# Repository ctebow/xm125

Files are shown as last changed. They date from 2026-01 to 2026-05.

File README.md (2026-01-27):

# XM125 Teensy Radar Project

This repository contains the files for a custom PCB project that integrates Acconeer's XM125 radar sensor with a Teensy microcontroller.

## Hardware

Here are some pictures of the physical setup.

### Front
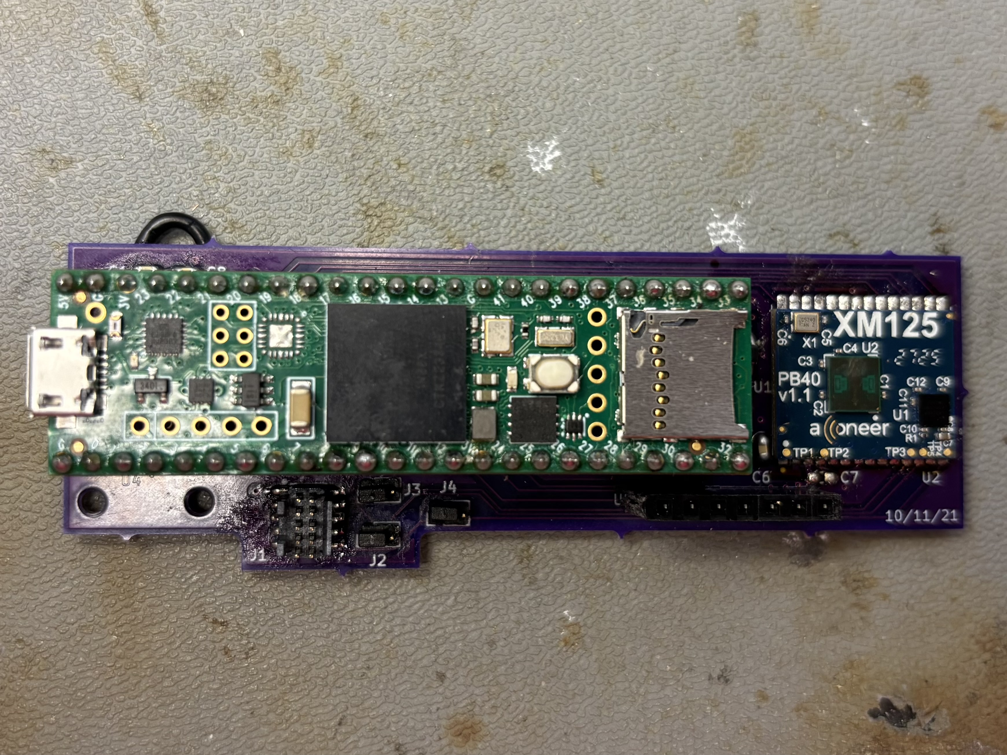
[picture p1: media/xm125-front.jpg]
Front View of the XM125 Teensy Setup


### Back
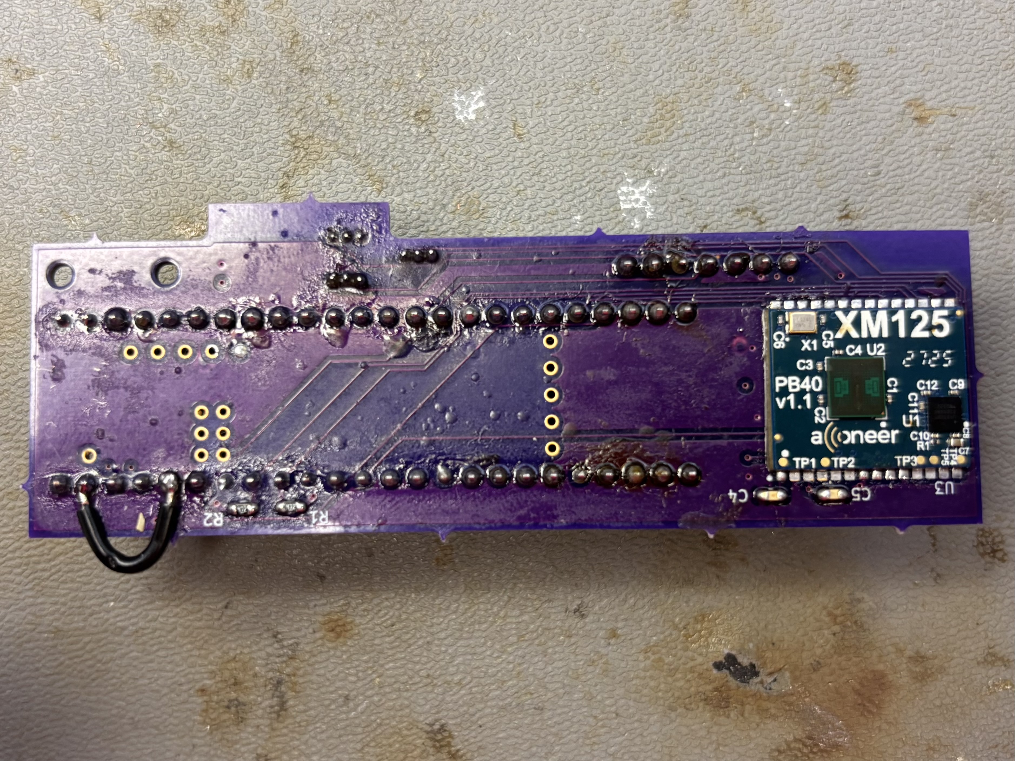
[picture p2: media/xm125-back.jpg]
Back View of the XM125 Teensy Setup


## PCB Schematic

The schematic for the custom PCB is shown below. This board breaks out the necessary connections for the XM125 radar sensor and provides a platform for development with a Teensy.

PCB Schematic

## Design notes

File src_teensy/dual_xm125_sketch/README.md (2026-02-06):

# Dual XM125 Sketch

Teensy sketch for two XM125 distance modules on I2C:

- **Front**: address 0x51, WAKE pin 20
- **Back**: address 0x52, WAKE pin 15

## Serial Protocol

Same protocol as `static_testing_sketch`, compatible with `benchmarking/scripts/serial_data_collection.py`:

- Send `START\n` to begin measurement loop
- Send `STOP\n` to end
- Each output line: `register rdistance strength` (space-separated)

**Register encoding:**

- `0–9`: Back sensor peaks 0–9  
- `10–19`: Front sensor peaks 0–9  

The Python script writes CSV: `trial, register, rdistance, strength, edistance`.

## Usage

1. Flash this sketch to a Teensy.
2. Wire both XM125 modules (front 0x51, back 0x52) and WAKE pins.
3. Run:

   ```bash
   python benchmarking/scripts/serial_data_collection.py -o output.csv -n 100 --num_trials 14 --edistance "200,190,180,170,160,150,140,130,120,110,100,90,80,70"
   ```

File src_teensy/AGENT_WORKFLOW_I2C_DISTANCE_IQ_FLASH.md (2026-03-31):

# Agent Workflow: I2C Distance + IQ on STM32L431 (FLASH Slimming)

## Context
- Target: `STM32L431CBYx` (128 KB FLASH, 64 KB RAM)
- Problem: Firmware build for an I2C Distance + IQ endpoint exceeded FLASH (initially ~112 bytes, later narrowed as refactors landed).
- Root cause of initial overflow: the IQ app duplicated large portions of the distance detector implementation in a second translation unit.

## Files & key building blocks used in the workflow
- Shared core API header (new): `Inc/i2c_distance_detector_core.h`
- Shared core implementation (new): `Src/applications/i2c/i2c_distance_detector_core.c`
- Custom trimmed core (new): `Src/applications/i2c/i2c_distance_detector_core_custom.c`
- Thin IQ endpoint app layer:
  - `Src/applications/i2c/i2c_iq_custom.c` (refactored to be a thin IQ endpoint on top of the core)
  - IQ stream variant exists in repo for reference:
    - `Src/applications/i2c/i2c_distance_iq_stream.c`
- I2C register protocol:
  - `Inc/distance_reg_protocol.h`
  - `Src/applications/i2c/distance_reg_protocol_access.c`

## Workflow steps (what to do, and why)
### 1) Stop duplication: split detector into “core + thin app”
Goal: ensure the distance detector logic is compiled once into FLASH.

Approach:
- Move detector lifecycle, state, and default command handling into:
  - `i2c_distance_detector_core.c`
- Make app selection work via weak symbols:
  - core provides default detector API behavior
  - IQ endpoint app provides strong overrides for IQ-specific command/data/status behaviors

### 2) Resolve “multiple definition” linker errors (weak exports)
Symptom:
- `multiple definition of i2c_distance_detector_*` when both core and an app compiled strong definitions.

Fix strategy:
- Mark core’s exported detector API functions as `__attribute__((weak))` so the app’s strong versions can override them.
- Ensure each CubeIDE configuration links exactly one “core” implementation object:
  - either `i2c_distance_detector_core.c` or `i2c_distance_detector_core_custom.c`, but not both.

### 3) Verify map evidence instead of guessing
Primary tool:
- CubeIDE link map file: `Debug/xm125.map`

What to inspect:
- `.rodata` contributors to understand string/format-string blowups.
- `_sidata` load address and `.data` section sizing to understand when the binary exceeds FLASH due to init-data placement.

Key realizations during this workflow:
- The custom IQ app’s `.rodata` was significantly larger than the stock detector app.
- After structural refactors and `.rodata` trimming, the failure mode shifted from `.rodata` overflow to `.data` load placement overflow.
- Remaining overflow can still be caused by library/code pulled in by IQ capture/processing paths.

### 4) Trim the remaining optional core features without touching the original core
New file introduced:
- `Src/applications/i2c/i2c_distance_detector_core_custom.c`

High-confidence cuts applied in the custom core:
- Removed auto “measure on wakeup” behavior.
- Removed UART log toggling and verbose logging paths (measurement print became a no-op).
- Removed config logging command support.
- Kept the critical detector lifecycle:
  - create config + sensor
  - apply config
  - calibrate / recalibrate
  - handle `MEASURE_DISTANCE`
  - maintain status and call `i2c_distance_detector_core_on_measurement_done()`

### 5) Handle “debug build warnings” safely
Warnings encountered:
- `is_detector_ready` defined but not used (`-Wunused-function`)
- ELF `LOAD segment with RWX permissions`

Guidance:
- If code paths were removed intentionally (e.g., wakeup auto-measure), unused helpers are expected.
- RWX load segment warnings are typical in bare-metal firmware with linker script memory permission attributes; ensure you’re not actually executing from `.data`.

## “Agent checklist” for future builds
1. Confirm your CubeIDE build links the intended core object and only one core object.
2. If link errors occur:
   - multiple definitions: apply weak-export strategy on the core side
   - FLASH overflow: inspect `Debug/xm125.map` for top `.rodata` and `.data` contributors
3. Cut optional features first (wakeup behavior, config logging, UART toggles).
4. Prefer structural sharing (core vs thin app) over string-only trimming.
5. When you get close (tens to hundreds of bytes):
   - compare `_sidata`, `.rodata`, and library pull-in (e.g., float/math paths) via the map.

## Summary of what was changed/added in this workflow
- Added: `Inc/i2c_distance_detector_core.h`
- Added: `Src/applications/i2c/i2c_distance_detector_core.c`
- Added: `Src/applications/i2c/i2c_distance_detector_core_custom.c` (trimmed optional features)
- Edited: `Src/applications/i2c/i2c_iq_custom.c` to become thin on top of the core
- Adjusted: core exported detector API functions to be `weak` to prevent multiple definition conflicts

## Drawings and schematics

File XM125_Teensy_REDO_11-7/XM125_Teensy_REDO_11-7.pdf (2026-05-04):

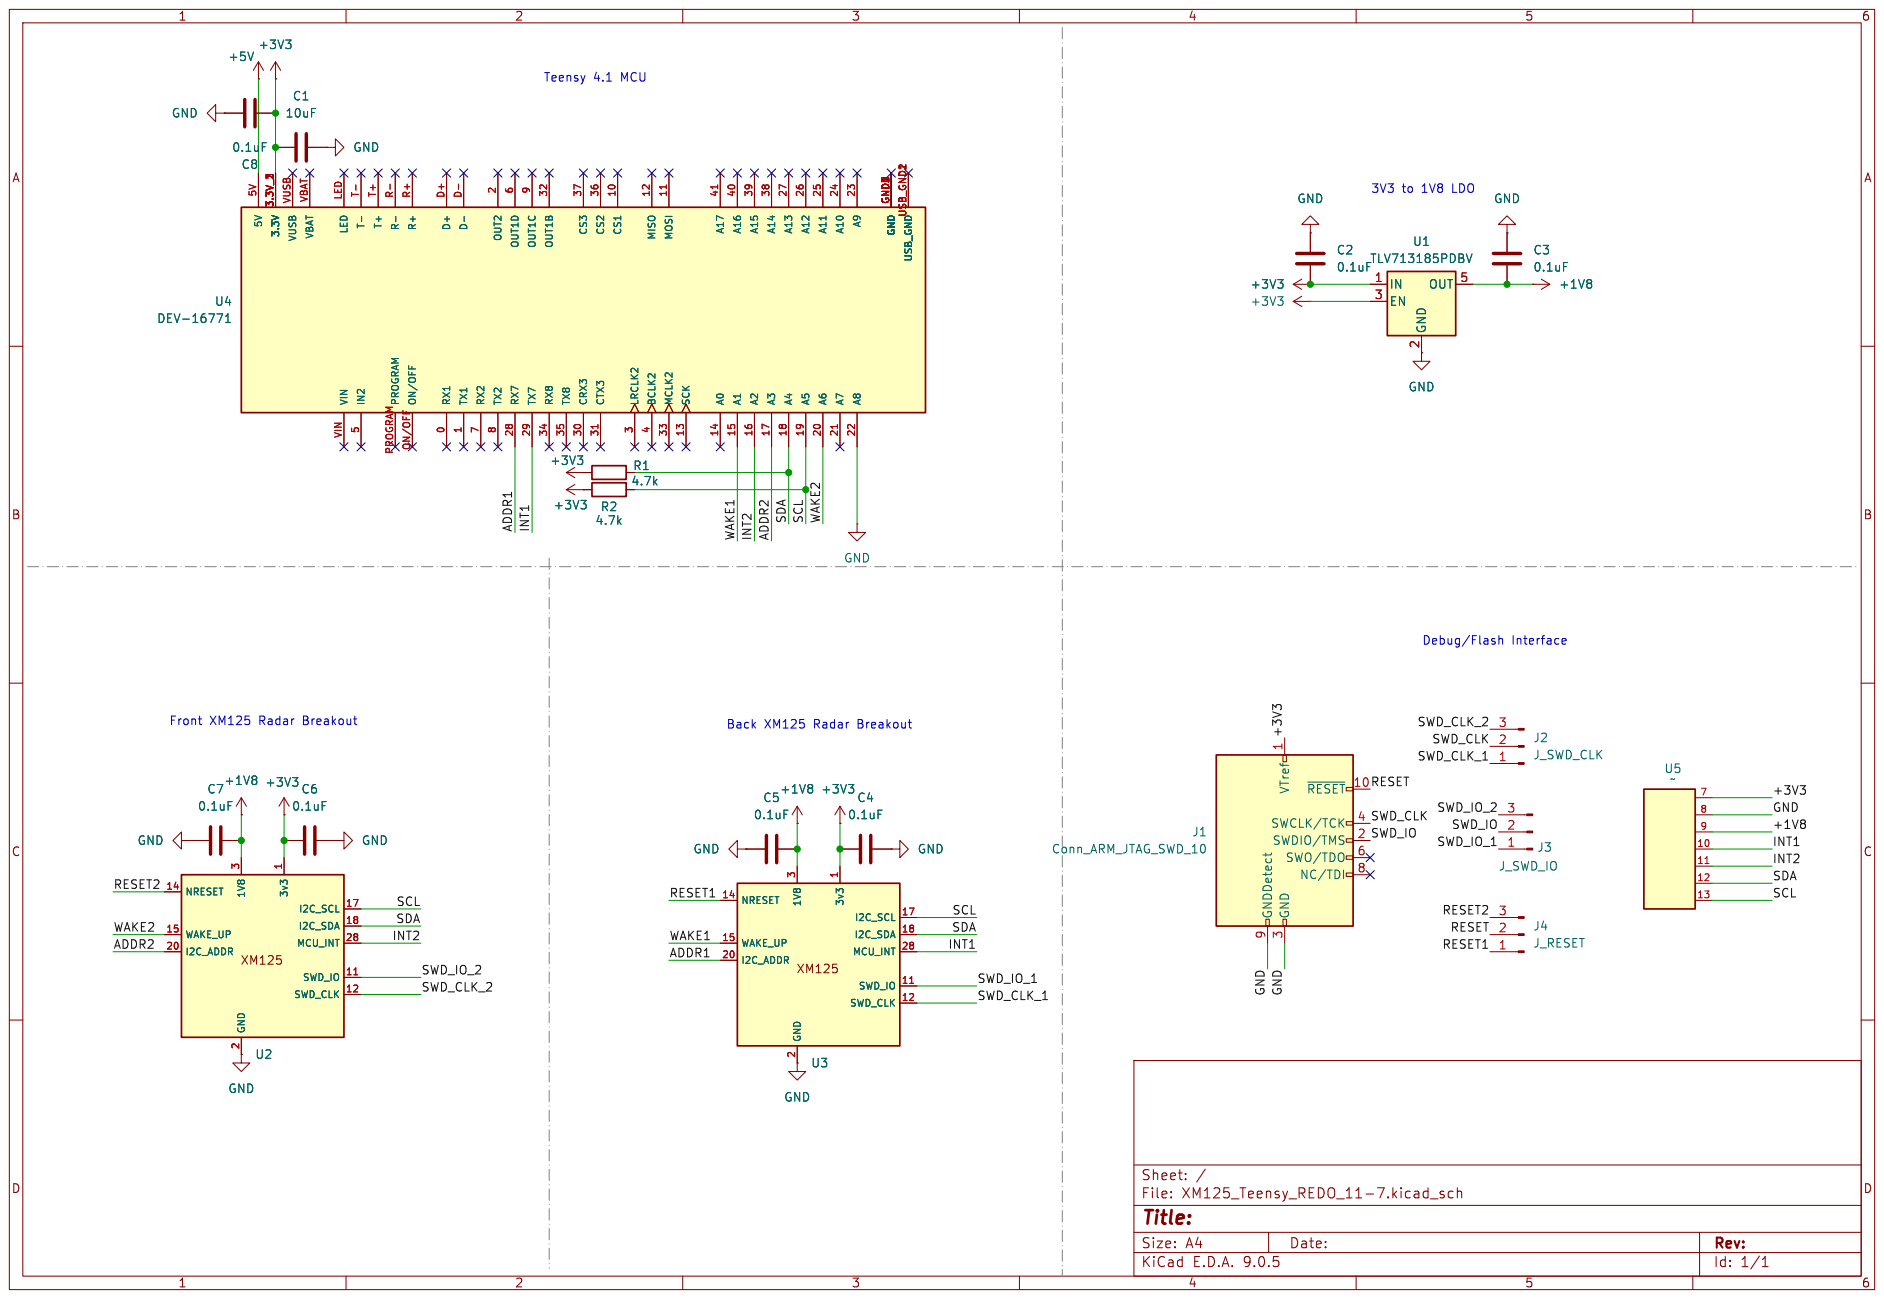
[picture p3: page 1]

4 MCLK2 33 SCK 13 A0 14 A1 15 A2 16 A3 17 A4 18 A5 19 A6 20 A7 21 A8 22 5V 5V 3.3V 3.3V_12 3.3V_3 VUSB VUSB VBAT VBAT LED LED T- T- T+ T+ R- R- R+ R+ D+ D+ D- D- OUT2

5 PROGRAM PROGRAMON/OFF ON/OFF RX1

3 ~{RESET}10 SWCLK/TCK 4 SWDIO/TMS 2 SWO/TDO 6 NC/TDI 8

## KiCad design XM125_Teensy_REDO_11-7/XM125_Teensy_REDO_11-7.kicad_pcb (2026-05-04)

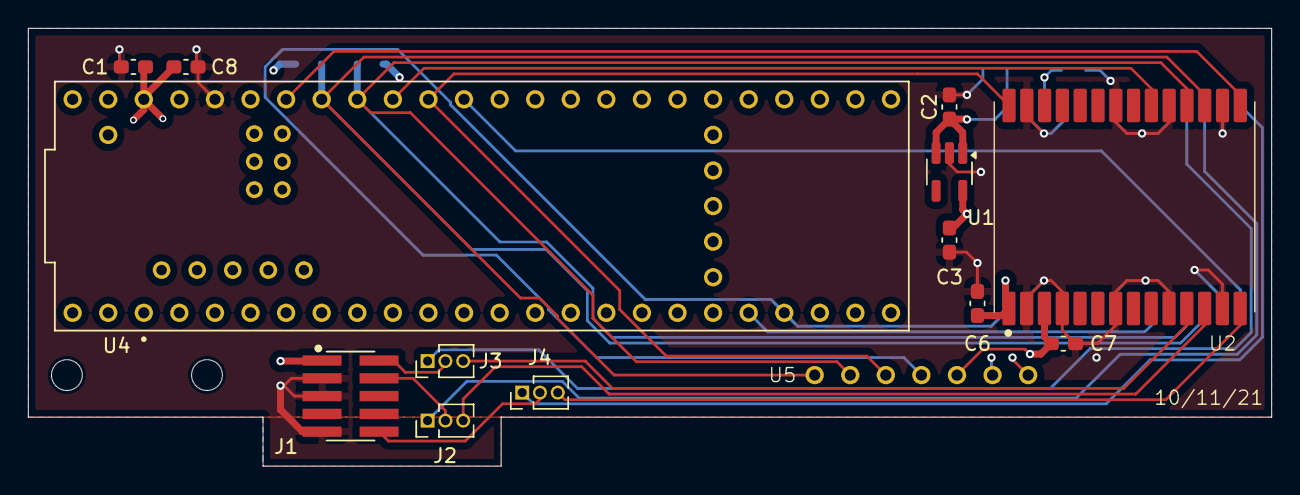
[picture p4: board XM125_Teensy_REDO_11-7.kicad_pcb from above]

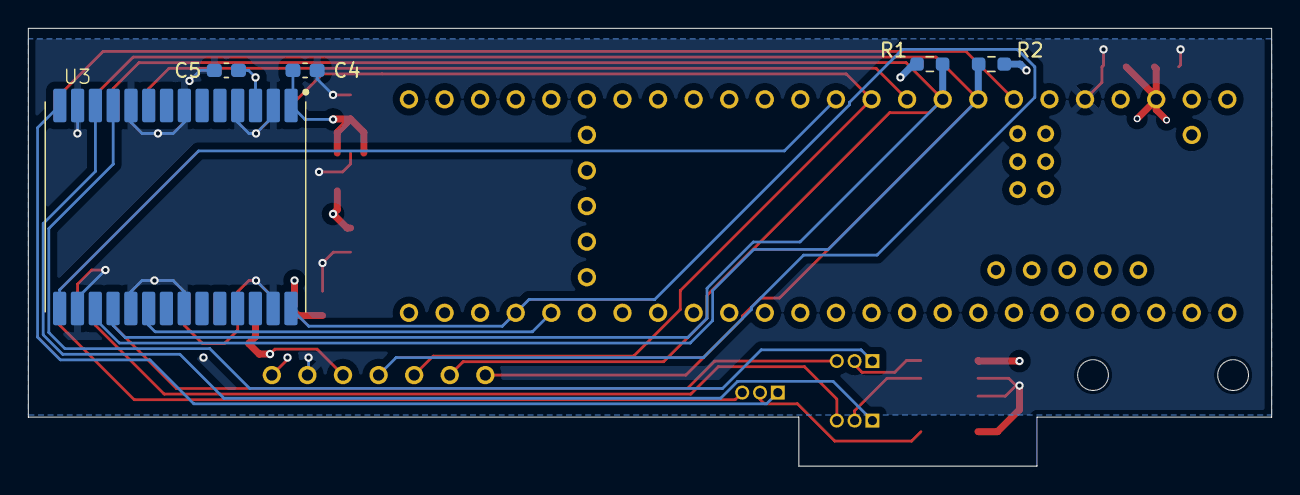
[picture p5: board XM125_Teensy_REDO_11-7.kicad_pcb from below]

Board: 4 copper layers, 88.8 x 31.2 mm, 19 parts (5 on the bottom side), 20 nets.

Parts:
C1: 10uF; C_0603_1608Metric_Pad1.08x0.95mm_HandSolder
C2, C3, C4, C5, C6, C7, C8: 0.1uF; C_0603_1608Metric_Pad1.08x0.95mm_HandSolder
J1: Conn_ARM_JTAG_SWD_10; FTS-105-03-L-DV
J2: J_SWD_CLK; PinHeader_1x03_P1.27mm_Vertical
J3: J_SWD_IO; PinHeader_1x03_P1.27mm_Vertical
J4: J_RESET; PinHeader_1x03_P1.27mm_Vertical
R1, R2: 4.7k; R_0603_1608Metric_Pad0.98x0.95mm_HandSolder
U1: TLV713185PDBV; SOT-23-5_HandSoldering
U2, U3: XM125
U4: DEV-16771; MODULE_DEV-16771
U5: Debug

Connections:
+1V8: C3.1, C5.1, C7.1, U1.5 (OUT), U2.3 (1V8), U3.3 (1V8), U5.9
+3V3: C1.1, C2.1, C4.2, C6.2, C8.1, J1.1 (VTref), R1.1, R2.1, U1.1 (IN), U1.3 (EN), U2.1 (3v3), U3.1 (3v3), U4.3.3V_1 (3.3V), U4.3.3V_2 (3.3V), U4.3.3V_3 (3.3V), U5.7
/ADDR1: U3.20 (I2C_ADDR), U4.28 (RX7)
/ADDR2: U2.20 (I2C_ADDR), U4.17 (A3)
/INT1: U3.28 (MCU_INT), U4.29 (TX7), U5.10
/INT2: U2.28 (MCU_INT), U4.16 (A2), U5.11
/RESET: J1.10 (~RESET), J4.2
/RESET1: J4.1, U3.14 (NRESET)
/RESET2: J4.3, U2.14 (NRESET)
/SCL: R2.2, U2.17 (I2C_SCL), U3.17 (I2C_SCL), U4.19 (A5), U5.13
/SDA: R1.2, U2.18 (I2C_SDA), U3.18 (I2C_SDA), U4.18 (A4), U5.12
/SWD_CLK: J1.4 (SWCLK/TCK), J2.2
/SWD_CLK_1: J2.1, U3.12 (SWD_CLK)
/SWD_CLK_2: J2.3, U2.12 (SWD_CLK)
/SWD_IO: J1.2 (SWDIO/TMS), J3.2
/SWD_IO_1: J3.1, U3.11 (SWD_IO)
/SWD_IO_2: J3.3, U2.11 (SWD_IO)
/WAKE1: U3.15 (WAKE_UP), U4.15 (A1)
/WAKE2: U2.15 (WAKE_UP), U4.20 (A6)
GND: C1.2, C2.2, C3.2, C4.1, C5.2, C6.1, C7.2, C8.2, J1.3 (GND), J1.5 (GND), J1.9 (GNDDetect), U1.2 (GND), U2.2 (GND), U2.4 (GND), U2.7 (GND), U2.10 (GND), U2.13 (GND), U2.16 (GND), U2.19 (GND), U2.22 (GND), U2.27 (GND), U3.2 (GND), U3.4 (GND), U3.7 (GND), U3.10 (GND), U3.13 (GND), U3.16 (GND), U3.19 (GND), U3.22 (GND), U3.27 (GND), U4.22 (A8), U5.8

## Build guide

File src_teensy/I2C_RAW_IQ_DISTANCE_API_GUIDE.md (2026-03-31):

# High-Level API Guide: Requesting Raw IQ Distance Frames over I2C

## What this guide covers
- The MCU/host communicates with the STM32 firmware via the I2C “distance detector” register protocol.
- This project supports two IQ endpoint styles:
  - `i2c_iq_custom.c`: IQ request is index-based (you request a bin/index and firmware captures and selects that index).
  - `i2c_distance_iq_stream.c`: IQ request is “capture once, then stream packed IQ samples”.

The register map comes from:
- `Inc/distance_reg_protocol.h`
- `Src/applications/i2c/distance_reg_protocol_access.c`

## Register addresses (subset)
- `DISTANCE_REG_COMMAND_ADDRESS` = `256`
- `DISTANCE_REG_DETECTOR_STATUS_ADDRESS` = `3`
- `DISTANCE_REG_MEASURE_COUNTER_ADDRESS` = `2`
- `DISTANCE_REG_PEAK0_DISTANCE_ADDRESS` = `17`
- `DISTANCE_REG_PEAK0_STRENGTH_ADDRESS` = `27`

## Command write behavior
- Writing a 32-bit value to `DISTANCE_REG_COMMAND_ADDRESS` triggers `i2c_distance_detector_command(value)`.
- Firmware sets a BUSY bit in detector status while processing.
- Host should wait until BUSY clears before reading results.

## IQ readiness signaling
- IQ readiness is communicated via bit `1<<16` in `DISTANCE_REG_DETECTOR_STATUS_ADDRESS`.
- Different IQ endpoint styles use different packing for the actual IQ samples, but the “IQ-ready bit” concept is consistent.

## IQ endpoint style A: `i2c_iq_custom.c` (index-based I/Q)
### IQ request format
- IQ command is written using:
  - upper 16 bits: `IQ_CMD_BASE` (value `6`)
  - lower 16 bits: requested `index`
- Firmware captures IQ and stores averaged IQ for all bins, then sets:
  - “current index” = requested index

### Sequence (one IQ bin)
1. Ensure detector is configured & calibrated for distance measurements.
2. Write command word to `DISTANCE_REG_COMMAND_ADDRESS`:
   - `command = (6<<16) | index`
3. Wait for the detector BUSY bit to clear.
4. Poll/read:
   - `DISTANCE_REG_DETECTOR_STATUS_ADDRESS` and confirm IQ-ready bit is set.
5. Read:
   - `DISTANCE_REG_MEASURE_COUNTER_ADDRESS`:
     - in this endpoint style it returns `iq_num_points` (#bins) when IQ is valid
   - `DISTANCE_REG_PEAK0_DISTANCE_ADDRESS`:
     - returns IQ “real” for the selected `index`
   - `DISTANCE_REG_PEAK0_STRENGTH_ADDRESS`:
     - returns IQ “imag” for the selected `index`

### Scaling of IQ values
- The protocol converts firmware `float` values to register values using `acc_reg_protocol_float_to_uint32_milli` / `acc_reg_protocol_float_to_int32_milli`.
- Practically:
  - divide read register integers by `1000` to recover the `float` IQ real/imag values.

### Getting a full IQ frame
- This endpoint style re-captures when you send a new IQ command.
- To retrieve the whole IQ frame, loop `index = 0 .. (iq_num_points-1)` and repeat the command + read steps for each index.

## IQ endpoint style B: `i2c_distance_iq_stream.c` (capture-once, stream packed IQ)
### IQ request format
- Firmware supports a command value `CAPTURE_IQ` with numeric value `6`.
- Host writes `DISTANCE_REG_COMMAND_ADDRESS = 6` to trigger capture.

### Sequence (capture once, then stream)
1. Ensure detector is configured & calibrated.
2. Write command:
   - `DISTANCE_REG_COMMAND_ADDRESS = 6`
3. Wait for IQ-ready bit to be set in `DISTANCE_REG_DETECTOR_STATUS_ADDRESS`.
4. Read `DISTANCE_REG_MEASURE_COUNTER_ADDRESS`:
   - IQ_METADATA is packed into this register:
     - valid bit (bit 31)
     - frame length (bits 0–15 in 16-bit words)
     - number of sweeps (bits 16–23)
     - data format (bits 24–29)
5. Stream IQ samples using `DISTANCE_REG_PEAK0_DISTANCE_ADDRESS` reads:
   - Each read returns a packed 32-bit word interpreted by firmware as:
     - low 16 bits = I (real)
     - high 16 bits = Q (imag)
   - The firmware returns a `float` that the protocol converts back to the packed integer, so host receives the packed IQ directly in the register value.

## Practical notes
- If you are optimizing for firmware size, prefer the “core + thin app” approach already used in this repo.
- If timing is critical, use the IQ stream style (capture once, stream many reads) rather than index-based repeated captures.

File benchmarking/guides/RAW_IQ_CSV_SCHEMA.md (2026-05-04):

# Raw IQ CSV schema

CSV files produced by [`benchmarking/scripts/get_iq_main.py`](../scripts/get_iq_main.py) when collecting from Teensy firmware [`raw_iq_xm125`](../../src_teensy/raw_iq_xm125/raw_iq_xm125.ino) (START/STOP) and [`RawI2CIqProtocol.h`](../../src_teensy/raw_iq_xm125/RawI2CIqProtocol.h) serial framing.

## File format

| Property | Value |
|---|---|
| **Encoding** | UTF-8 |
| **Delimiter** | Comma (`,`) |
| **Header row** | Yes — first row is the column header |
| **Row grain** | One row per **range bin** (one `bin_index I Q` line from serial) |

## Column definitions

Columns appear in this **fixed order**:

| # | Column | Type | Description |
|---|---|---|---|
| 1 | `trial` | integer | 0-based collection trial index (`--trials`). |
| 2 | `host_frame_id` | string | Teensy `frameCounter` from the `FRAME` serial line (host-side frame counter). |
| 3 | `sensor` | string | Sensor label from `FRAME`, e.g. `BACK`, `FRONT`. |
| 4 | `i2c_addr_hex` | string | Value after `addr=` on `FRAME` (hex digits without `0x` prefix in the cell, matching firmware print). |
| 5 | `bins` | string | Value after `bins=` on `FRAME`: number of bins in that IQ frame. |
| 6 | `firmware_frame_id` | string | Value after `fid=` on `FRAME`: STM firmware IQ cache frame id. |
| 7 | `t_ms` | string | Value after `t_ms=` on `FRAME`: Teensy `millis()` when the frame header was printed. |
| 8 | `bin_index` | string or numeric | First field of the bin line — global register index (back often `0..N-1`; front continues from `N` when both sensors are enabled). |
| 9 | `I` | float | In-phase component (Teensy sends floats already scaled from register milli-units). |
| 10 | `Q` | float | Quadrature component (same as `I`). |
| 11 | `expected_distance_mm` | float or empty | Optional experiment metadata from `--expected-distance-mm` for that trial; **empty** if not supplied. |

## Serial mapping

Teensy prints:

1. **Frame header:** `FRAME <host_frame_id> <SENSOR> addr=0xXX bins=<N> fid=<firmware_fid> t_ms=<millis>`
2. **Bin rows:** `<bin_index> <I> <Q>` (repeated `bins` times)
3. **Frame footer:** `ENDFRAME <host_frame_id> <SENSOR>`

Each bin row becomes one CSV row. Metadata columns (`host_frame_id` through `t_ms`) are **duplicated** from the most recent `FRAME` line so analysis does not need to join separate metadata files.

## Collection modes

| Mode | CLI | Row selection |
|---|-----|---|
| By IQ frames | `--num-iq-frames N` | Only bin rows **between** a `FRAME` and matching `ENDFRAME`; stop after `N` complete frame blocks. |
| By bin count | `--num-bin-rows N` | Stop after `N` bin rows. If no `FRAME` has been seen yet, frame metadata columns may be **empty** until the first `FRAME` is parsed. |

## Grouping for analysis

Treat rows as belonging to one **logical IQ frame** when they share the same:

- `trial`
- `host_frame_id`
- `sensor`
- `firmware_frame_id` (and typically the same `bins` and `t_ms` from that `FRAME`)

Across bins within that frame, `firmware_frame_id` should stay constant for a coherent cached capture on the STM side.

## Example header row

```csv
trial,host_frame_id,sensor,i2c_addr_hex,bins,firmware_frame_id,t_ms,bin_index,I,Q,expected_distance_mm
```

## Related

- I2C / firmware IQ protocol: [I2C_RAW_IQ_DISTANCE_API_GUIDE.md](I2C_RAW_IQ_DISTANCE_API_GUIDE.md)
- Collector CLI: `python benchmarking/scripts/get_iq_main.py --help`

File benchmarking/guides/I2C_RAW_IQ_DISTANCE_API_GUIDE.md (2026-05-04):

# I2C Raw IQ Distance API Guide (Cached Robust Variant)

This guide targets firmware built with:

- `Src/applications/i2c/i2c_iq_custom_cache_robust.c`

It explains the best host/master flow to fetch raw IQ over a constrained I2C link while preserving single-frame coherency.

## Overview

The robust cached IQ variant behaves as follows:

- IQ command namespace is `op = 6` in the high 16 bits of the command register value.
- On first IQ request when cache is invalid, the module captures one frame and caches per-bin averaged I/Q.
- Further IQ requests only move the selected bin index and read from that same cached frame.
- Cache is invalidated when detector state-changing commands run (`APPLY_CONFIGURATION`, `CALIBRATE`, `RECALIBRATE`, `APPLY_CONFIG_AND_CALIBRATE`, `MEASURE_DISTANCE`).
- Cache can also be explicitly invalidated by host with IQ index `0xFFFF`.

## Register Usage

Use the existing distance register map:

- `DISTANCE_REG_COMMAND_ADDRESS` (`256`): write command words.
- `DISTANCE_REG_DETECTOR_STATUS_ADDRESS` (`3`): read detector and IQ status bits.
- `DISTANCE_REG_MEASURE_COUNTER_ADDRESS` (`2`): read IQ metadata when cache is valid.
- `DISTANCE_REG_PEAK0_DISTANCE_ADDRESS` (`17`): current selected bin I (real), scaled x1000 in transport.
- `DISTANCE_REG_PEAK0_STRENGTH_ADDRESS` (`27`): current selected bin Q (imag), scaled x1000 in transport.

## Command Encoding

Command payload is 32-bit:

- `op` = upper 16 bits
- `index` = lower 16 bits

For IQ:

- `command = (6 << 16) | bin_index`
- Explicit invalidate:
  - `command = (6 << 16) | 0xFFFF`

## Status Bits (Robust Variant)

Read `DETECTOR_STATUS` and inspect:

- `IQ_READY` = bit 30 (`1 << 30`)
- `IQ_CAPTURE_ERROR` = bit 29 (`1 << 29`)

These are chosen to avoid overlap with protocol-defined detector error/status fields.

## MEASURE_COUNTER Interpretation (Robust Variant)

When IQ cache is valid, `MEASURE_COUNTER` returns:

- low 16 bits: `iq_num_points` (available bins)
- high 16 bits: `iq_frame_id` (increments on successful fresh capture)

When IQ cache is not valid, behavior falls back to default distance measure counter.

## Recommended Host Flow

1. Ensure detector is configured and calibrated.
2. Trigger IQ capture/select start bin:
   - write `COMMAND = (6 << 16) | 0`
3. Poll `DETECTOR_STATUS` until:
   - `IQ_READY == 1`
   - `IQ_CAPTURE_ERROR == 0`
4. Read `MEASURE_COUNTER`:
   - `frame_id_start = (counter >> 16) & 0xFFFF`
   - `num_bins = counter & 0xFFFF`
5. For each `bin` in `[0, num_bins-1]`:
   - write `COMMAND = (6 << 16) | bin`
   - read `PEAK0_DISTANCE` => `I_milli`
   - read `PEAK0_STRENGTH` => `Q_milli`
   - convert to float:
     - `I = I_milli / 1000.0`
     - `Q = Q_milli / 1000.0`
6. Re-read `MEASURE_COUNTER` and compare frame id:
   - `frame_id_end = (counter2 >> 16) & 0xFFFF`
   - if `frame_id_end != frame_id_start`, discard and retry capture sequence.

## Throughput Tips for Slow I2C

- Keep one capture and stream all bins from cache; do not force recapture between bins.
- Avoid unnecessary status polls during steady bin reads once cache is ready.
- Use sequential register reads where practical to reduce transaction overhead.
- Use fixed retry windows and bounded poll intervals for deterministic benchmark timing.

## Error Handling

If `IQ_CAPTURE_ERROR` is set:

1. Optionally send explicit invalidate command: `(6 << 16) | 0xFFFF`
2. Retry IQ capture command `(6 << 16) | desired_index`
3. If failures persist:
   - verify detector ready/configured/calibrated state
   - verify sensor IRQ timing and host timeout budget

## Notes

- Exported IQ length may be capped by firmware (`IQ_MAX_POINTS`), even if raw frame has more bins.
- Robust indexing in firmware uses full frame stride internally, so truncated export still preserves correct bin mapping.

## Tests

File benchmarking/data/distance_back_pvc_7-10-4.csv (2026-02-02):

trial | register | rdistance | strength | edistance
0 | 0.0 | 90.0 | -7729.0 | 100
0 | 1.0 | 252.0 | 2318.0 | 100
0 | 0.0 | 90.0 | -8100.0 | 100
0 | 1.0 | 251.0 | 2473.0 | 100
0 | 0.0 | 90.0 | -7727.0 | 100
0 | 1.0 | 252.0 | 2949.0 | 100
0 | 0.0 | 91.0 | -7831.0 | 100
0 | 1.0 | 252.0 | 3348.0 | 100
0 | 0.0 | 90.0 | -7729.0 | 100
0 | 1.0 | 251.0 | 3263.0 | 100
0 | 0.0 | 90.0 | -7683.0 | 100
0 | 1.0 | 252.0 | 2717.0 | 100
0 | 0.0 | 89.0 | -7903.0 | 100
0 | 1.0 | 252.0 | 3307.0 | 100
0 | 0.0 | 90.0 | -7788.0 | 100
0 | 1.0 | 251.0 | 3123.0 | 100
0 | 0.0 | 90.0 | -7824.0 | 100
0 | 1.0 | 252.0 | 3634.0 | 100
0 | 0.0 | 90.0 | -7970.0 | 100
0 | 1.0 | 251.0 | 3376.0 | 100
0 | 0.0 | 90.0 | -7931.0 | 100
0 | 1.0 | 251.0 | 2893.0 | 100
0 | 0.0 | 90.0 | -7666.0 | 100
0 | 1.0 | 251.0 | 2735.0 | 100
0 | 0.0 | 90.0 | -7975.0 | 100
0 | 1.0 | 252.0 | 2474.0 | 100
0 | 0.0 | 90.0 | -7842.0 | 100
0 | 1.0 | 253.0 | 3347.0 | 100
0 | 0.0 | 90.0 | -7775.0 | 100
0 | 1.0 | 251.0 | 3015.0 | 100
0 | 0.0 | 90.0 | -7727.0 | 100
0 | 1.0 | 251.0 | 3203.0 | 100
0 | 0.0 | 90.0 | -7847.0 | 100
0 | 1.0 | 252.0 | 3032.0 | 100
0 | 0.0 | 90.0 | -7911.0 | 100
0 | 1.0 | 252.0 | 3374.0 | 100
0 | 0.0 | 90.0 | -7710.0 | 100
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

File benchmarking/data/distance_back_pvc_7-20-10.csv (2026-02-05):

trial | register | rdistance | strength | edistance
0 | 0.0 | 58.0 | -13990.0 | 200
0 | 1.0 | 203.0 | -17263.0 | 200
0 | 0.0 | 58.0 | -14048.0 | 200
0 | 1.0 | 204.0 | -17390.0 | 200
0 | 0.0 | 58.0 | -14063.0 | 200
0 | 1.0 | 204.0 | -17145.0 | 200
0 | 0.0 | 58.0 | -13929.0 | 200
0 | 1.0 | 203.0 | -17511.0 | 200
0 | 0.0 | 58.0 | -13993.0 | 200
0 | 1.0 | 202.0 | -17750.0 | 200
0 | 0.0 | 58.0 | -13925.0 | 200
0 | 1.0 | 204.0 | -17351.0 | 200
0 | 0.0 | 57.0 | -13832.0 | 200
0 | 1.0 | 203.0 | -17605.0 | 200
0 | 0.0 | 57.0 | -13918.0 | 200
0 | 1.0 | 204.0 | -17515.0 | 200
0 | 0.0 | 57.0 | -14022.0 | 200
0 | 1.0 | 203.0 | -17625.0 | 200
0 | 0.0 | 57.0 | -13939.0 | 200
0 | 1.0 | 204.0 | -17519.0 | 200
0 | 0.0 | 57.0 | -13855.0 | 200
0 | 1.0 | 204.0 | -17545.0 | 200
0 | 0.0 | 58.0 | -14094.0 | 200
0 | 1.0 | 203.0 | -17553.0 | 200
0 | 0.0 | 57.0 | -13966.0 | 200
0 | 1.0 | 199.0 | -17209.0 | 200
0 | 0.0 | 58.0 | -14054.0 | 200
0 | 1.0 | 203.0 | -17406.0 | 200
0 | 0.0 | 58.0 | -13922.0 | 200
0 | 1.0 | 201.0 | -17479.0 | 200
0 | 0.0 | 58.0 | -13942.0 | 200
0 | 1.0 | 204.0 | -17440.0 | 200
0 | 0.0 | 57.0 | -13973.0 | 200
0 | 1.0 | 204.0 | -17510.0 | 200
0 | 0.0 | 57.0 | -13932.0 | 200
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

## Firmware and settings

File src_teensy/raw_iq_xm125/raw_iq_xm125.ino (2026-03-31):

/*
 * raw_iq_xm125
 *
 * Teensy Arduino sketch for validating the flashed XM125 raw-IQ firmware.
 *
 * - Controls two XM125 modules on I2C:
 *   - Back: 0x52, WAKE pin 15
 *   - Front: 0x51, WAKE pin 20
 * - Uses the SparkFun XM125 library for the distance detector lifecycle:
 *   - reset/configure
 *   - start detector
 *   - calibration handling
 * - Uses raw `Wire` register reads/writes for the custom IQ endpoints:
 *   - stream-B style IQ capture
 *
 * Serial protocol:
 * - Send `START\n` to begin measurement loop
 * - Send `STOP\n` to end
 * - For each IQ sample printed one per line:
 *     `registerIndex I Q`
 *   where registerIndex is unique across back+front sensors:
 *     - back:  0..N-1
 *     - front: N..N+M-1
 */

#include "SparkFun_Qwiic_XM125_Arduino_Library.h"
#include <Arduino.h>
#include "DistanceReader.h"
#include "RawI2CIqProtocol.h"

// I2C addresses
static constexpr uint8_t FRONT_I2C_ADDR = 0x51;
static constexpr uint8_t BACK_I2C_ADDR = 0x52;

// Wake pins (must be HIGH for STM32 to respond)
static constexpr uint8_t WAKE_FRONT_PIN = 20;
static constexpr uint8_t WAKE_BACK_PIN = 15;

static constexpr size_t CMD_BUF_SIZE = 16;
static constexpr uint32_t IQ_HARD_LIMIT_SAMPLES = 4096;

SparkFunXM125Distance sensorFront;
SparkFunXM125Distance sensorBack;

static bool measuring = false;
static bool efront = false;
static bool eback = true;
static uint32_t frameCounter = 0;

static char cmd_buffer[CMD_BUF_SIZE];
static uint8_t cmd_index = 0;

static uint32_t errorStatus = 0;
static uint32_t measDistErr = 0;
static uint32_t calibrateNeeded = 0;
static uint32_t startVal = 0;
static uint32_t endVal = 0;

static bool initSensor(SparkFunXM125Distance& sensor, uint8_t i2cAddr, const char* name) {
    // #region agent log: i2c connectivity pre-check
    Serial.print("[I2C precheck] ");
    Serial.print(name);
    Serial.print(" addr=0x");
    Serial.print(i2cAddr, HEX);
    Serial.println();

    Wire.beginTransmission(i2cAddr);
    uint8_t wireErr = Wire.endTransmission();
    Serial.print("[I2C precheck] ");
    Serial.print(name);
    Serial.print(" Wire.endTransmission err=");
    Serial.println(wireErr);

    uint32_t detectorStatusRaw = 0;
    bool rawStatusOk = rawReadReg32(i2cAddr, DISTANCE_REG_DETECTOR_STATUS_ADDRESS, detectorStatusRaw);
    Serial.print("[I2C precheck] ");
    Serial.print(name);
    Serial.print(" rawReadReg32(detector_status) ok=");
    Serial.print(rawStatusOk ? "1" : "0");
    Serial.print(" val=0x");
    Serial.println(detectorStatusRaw, HEX);
    // #endregion agent log

    int beginOk = sensor.begin(i2cAddr, Wire);
    if (beginOk != 1) {
        // #region agent log: i2c connectivity failure diagnostics
        Serial.print("[I2C fail] ");
        Serial.print(name);
        Serial.print(" sensor.begin returned ");
        Serial.println(beginOk);

        // Try one more read of a known register (helps distinguish "no ACK" vs "SparkFun init mismatch").
        detectorStatusRaw = 0;
        rawStatusOk = rawReadReg32(i2cAddr, DISTANCE_REG_DETECTOR_STATUS_ADDRESS, detectorStatusRaw);
        Serial.print("[I2C fail] ");
        Serial.print(name);
        Serial.print(" retry rawReadReg32(detector_status) ok=");
        Serial.print(rawStatusOk ? "1" : "0");
        Serial.print(" val=0x");
        Serial.println(detectorStatusRaw, HEX);
        // #endregion agent log

        Serial.print(name);
        Serial.println(" could not connect over I2C - Freezing.");
        return false;
    }

    Serial.print("Connected: ");
    Serial.println(name);

    // Reset sensor configuration to reapply configuration registers.
    sensor.setCommand(SFE_XM125_DISTANCE_RESET_MODULE);
    Serial.println("Resetting sensor..");

    sensor.busyWait();

    // Check error and busy bits.
    sensor.getDetectorErrorStatus(errorStatus);
    if (errorStatus != 0) {
        Serial.print("Detector status error: ");
        Serial.println(errorStatus);
    }

    delay(100);

    configureSensor(sensor, errorStatus, startVal, endVal);

    if (sensor.busyWait() != 0) {
        Serial.print(name);
        Serial.println(" busy wait error");
    }
    sensor.getDetectorErrorStatus(errorStatus);
    if (errorStatus != 0) {
        Serial.print(name);
        Serial.print(" status error: ");
        Serial.println(errorStatus);
    }
    return true;
}

static void processSerialCommands() {
    while (Serial.available() > 0) {
        char c = Serial.read();

        if (c == '\n') {
            cmd_buffer[cmd_index] = '\0';
            if (strcmp(cmd_buffer, "START") == 0) {
                measuring = true;
            } else if (strcmp(cmd_buffer, "STOP") == 0) {
                measuring = false;
            }
            cmd_index = 0;
        } else if (c != '\r' && cmd_index < CMD_BUF_SIZE - 1) {
            cmd_buffer[cmd_index++] = c;
        }
    }
}

void setup() {
    Serial.begin(115200);
    Serial.println("raw_iq_xm125: front 0x51, back 0x52");
    Serial.println("Protocol: START/STOP; output: registerIndex I Q");
    Serial.println();

    pinMode(WAKE_FRONT_PIN, OUTPUT);
    pinMode(WAKE_BACK_PIN, OUTPUT);
    digitalWrite(WAKE_FRONT_PIN, HIGH);
    digitalWrite(WAKE_BACK_PIN, HIGH);

    Wire.begin();

    // #region agent log: i2c address scan (helps diagnose address pin mismatch)
    Serial.println("[I2C scan] probing addresses 0x50..0x54 for ACK");
    for (uint8_t addr = 0x50; addr <= 0x54; addr++) {
        Wire.beginTransmission(addr);
        uint8_t err = Wire.endTransmission();
        Serial.print("[I2C scan] addr=0x");
        Serial.print(addr, HEX);
        Serial.print(" err=");
        Serial.println(err);
    }
    // #endregion agent log

    if (eback) {
        if (!initSensor(sensorBack, BACK_I2C_ADDR, "Back (0x52)")) {
            while (1) {}
        }
    }

    if (efront) {
        if (!initSensor(sensorFront, FRONT_I2C_ADDR, "Front (0x51)")) {
            while (1) {}
        }
    }

    Serial.println("Ready. Send START to stream IQ.");
    delay(500);
}

void loop() {
    processSerialCommands();
    if (!measuring) {
        delay(250);
        return;
    }

    uint32_t iqSamplesBack = 0;
    bool recalibratedThisFrame = false;

    if (eback) {
        recalibratedThisFrame = false;
        checkErrorsAndStart(sensorBack, errorStatus, measDistErr, calibrateNeeded, recalibratedThisFrame, BACK_I2C_ADDR);
        // Stream IQ samples using style-A IQ endpoint; register indices start at 0 for the back sensor.
        captureIqStyleAAndPrint(BACK_I2C_ADDR, /*registerBase=*/0, iqSamplesBack, frameCounter++, "BACK", /*timeoutMs=*/5000, IQ_HARD_LIMIT_SAMPLES);
    }

    if (efront) {
        recalibratedThisFrame = false;
        checkErrorsAndStart(sensorFront, errorStatus, measDistErr, calibrateNeeded, recalibratedThisFrame, FRONT_I2C_ADDR);
        // Stream IQ samples; register indices start at N (back sample count).
        uint32_t dummy = 0;
        captureIqStyleAAndPrint(FRONT_I2C_ADDR, /*registerBase=*/iqSamplesBack, dummy, frameCounter++, "FRONT", /*timeoutMs=*/5000, IQ_HARD_LIMIT_SAMPLES);
    }

    delay(400);
}

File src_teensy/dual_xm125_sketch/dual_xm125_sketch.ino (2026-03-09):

/*
 * Dual XM125 distance sensor sketch
 *
 * Supports two XM125 modules on I2C:
 *   - Front: 0x51
 *   - Back:  0x52
 *
 * Serial protocol (for serial_data_collection.py):
 *   - Send "START\n" to begin measurement loop
 *   - Send "STOP\n" to end
 *   - Each line: "register rdistance strength recalibrated" (space-separated)
 *       * recalibrated: 1 if a recalibration command was applied for that frame, else 0
 *   - Register encoding: 0-9 = back peaks 0-9, 10-19 = front peaks 0-9
 *   - Python maps to CSV: trial, register, rdistance, strength, recalibrated, edistance
 */
#include "SparkFun_Qwiic_XM125_Arduino_Library.h"
#include <Arduino.h>
#include "DistanceReader.h"

// I2C addresses
static constexpr uint8_t FRONT_I2C_ADDR = 0x51;
static constexpr uint8_t BACK_I2C_ADDR  = 0x52;

// Wake pins (must be HIGH for STM32 to respond)
static constexpr uint8_t WAKE_FRONT_PIN = 20;
static constexpr uint8_t WAKE_BACK_PIN  = 15;

static constexpr size_t CMD_BUF_SIZE = 16;

SparkFunXM125Distance sensorFront;
SparkFunXM125Distance sensorBack;

bool measuring = false;
bool efront = true;
bool eback = true;
char cmd_buffer[CMD_BUF_SIZE];
uint8_t cmd_index = 0;

uint32_t errorStatus = 0;
uint32_t measDistErr = 0;
uint32_t calibrateNeeded = 0;
uint32_t startVal = 0;
uint32_t endVal = 0;

bool initSensor(SparkFunXM125Distance& sensor, uint8_t i2cAddr, const char* name) {
    if (sensor.begin(i2cAddr, Wire) != 1) {
        Serial.print(name);
        Serial.println(" could not connect over I2C - Freezing.");
        return false;
    }
    Serial.print("Connected: ");
    Serial.println(name);

    // Reset sensor configuration to reapply configuration registers
    sensor.setCommand(SFE_XM125_DISTANCE_RESET_MODULE);
    Serial.println("Resetting sensor..");

    sensor.busyWait();

    // Check error and busy bits
    sensor.getDetectorErrorStatus(errorStatus);
    if (errorStatus != 0)
    {
        Serial.print("Detector status error: ");
        Serial.println(errorStatus);
    }

    delay(100);

    configureSensor(sensor, errorStatus, startVal, endVal);

    if (sensor.busyWait() != 0) {
        Serial.print(name);
        Serial.println(" busy wait error");
    }
    sensor.getDetectorErrorStatus(errorStatus);
    if (errorStatus != 0) {
        Serial.print(name);
        Serial.print(" status error: ");
        Serial.println(errorStatus);
    }
    return true;
}

void processSerialCommands() {
    while (Serial.available() > 0) {
        char c = Serial.read();

        if (c == '\n') {
            cmd_buffer[cmd_index] = '\0';
            if (strcmp(cmd_buffer, "START") == 0) {
                measuring = true;
            } else if (strcmp(cmd_buffer, "STOP") == 0) {
                measuring = false;
            }
            cmd_index = 0;
        } else if (c != '\r' && cmd_index < CMD_BUF_SIZE - 1) {
            cmd_buffer[cmd_index++] = c;
        }
    }
}

// Output peaks to Serial in standardized format: "register rdistance strength"
// baseRegister: 0 for back, 10 for front (so register 0-9 = back, 10-19 = front)
void outputPeaks(SparkFunXM125Distance& sensor, uint8_t baseRegister, bool recalibrated) {
    uint32_t distances[NUM_PEAKS];
    int32_t strengths[NUM_PEAKS];
    readAllPeaks(sensor, distances, strengths);

    for (int i = 0; i < NUM_PEAKS; i++) {
        if (distances[i] != 0) {
            Serial.print(baseRegister + i);
            Serial.print(' ');
            Serial.print(distances[i]);
            Serial.print(' ');
            Serial.print(strengths[i]);
            Serial.print(' ');
            Serial.println(recalibrated ? 1 : 0);
        }
    }
}

void setup() {
    Serial.begin(115200);
    Serial.println("Dual XM125: front 0x51, back 0x52");
    Serial.println("Protocol: START/STOP, format: register rdistance strength");
    Serial.println();

    pinMode(WAKE_FRONT_PIN, OUTPUT);
    pinMode(WAKE_BACK_PIN, OUTPUT);
    digitalWrite(WAKE_FRONT_PIN, HIGH);
    digitalWrite(WAKE_BACK_PIN, HIGH);

    Wire.begin();
    if (eback) {
        if (!initSensor(sensorBack, BACK_I2C_ADDR, "Back (0x52)")) {
            while (1) {}
        }
    }

    if (efront) {
        if (!initSensor(sensorFront, FRONT_I2C_ADDR, "Front (0x51)")) {
            while (1) {}
        }
    }
    Serial.println("Ready. Send START to measure.");
    delay(500);
}

void loop() {
    processSerialCommands();

    if (measuring) {
        // Back sensor first (register 0-9)
        if (eback) {
            bool backRecalibrated = false;
            checkErrorsAndStart(sensorBack, errorStatus, measDistErr, calibrateNeeded, backRecalibrated);
            outputPeaks(sensorBack, 0, backRecalibrated);
        }
        // Front sensor (register 10-19)
        if (efront) {
            bool frontRecalibrated = false;
            checkErrorsAndStart(sensorFront, errorStatus, measDistErr, calibrateNeeded, frontRecalibrated);
            outputPeaks(sensorFront, 10, frontRecalibrated);
        }
    }

    delay(400);
}

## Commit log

2026-01-27 Add schematic image
2026-01-28 New python control script
    [test1.csv]
2026-01-30 Start Distance Benchmarking
    [distance_back_pvc_7-10-4.csv, distance_front_pvc_7-10-4.csv, test1.csv]
2026-01-30 Teensy Scripts
2026-02-02 Refactor in cursor
    [distance_back_pvc_7-10-4.csv]
2026-02-05 Benchmarked back sensor at mm and cm scale
    [distance_back_pvc_7-20-10.csv, distance_back_pvc_7-20-10_v2.csv]
2026-02-06 New dual control script for teensy
2026-02-20 Strength characterization woes
    [distance_dual_pvc_5-7-2.csv, dual_test_pvc.csv, strength_back_pvc_70mm_CFAR.csv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]
2026-02-24 Figuring things out
    [profile_back_greenpvc_60-100-2mm_profile1_snr15000_CFAR.csv, profile_back_greenpvc_90-145-5mm_profile1_snr35000_CFAR.csv, profile_back_greenpvc_90-145-5mm_prof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]
2026-03-02 More data taken --> conclude 2.5mm limit
    [profile_back_greenpvc_85-95-2mm_profile1_snr35000_CFAR.csv, profile_back_greenpvc_85-95-2mm_profile2_snr35000_CFAR.csv, profile_back_greenpvc_90-145-5mm_profil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]
2026-03-09 Started doing some dual testing
    [profile_dual_greenpvc_30-100-5mm_profile2_snr35000_CFAR.csv, profile_dual_greenpvc_30-110-5mm_s140mm_profile2_snr35000_CFAR.csv, profile_dual_greenpvc_30-110-5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]
2026-03-10 Update schematic and dual fitting
    [XM125_Teensy_REDO_11-7.kicad_pcb]
2026-03-31 Add new pipeline for capturing raw iq data
    [raw_iq_test.csv, raw_iq_test_2.csv, raw_iq_test_3.csv]
2026-05-04 create new data visualization pipeline
    [iqfc_static_test_1.csv, iqfc_static_test_2.csv, iqfc_static_test_3.csv]
